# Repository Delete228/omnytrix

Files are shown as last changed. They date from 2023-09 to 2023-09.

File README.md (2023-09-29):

# omnytrix
Часы как у Бена Теннисона из одноименного мультфильма
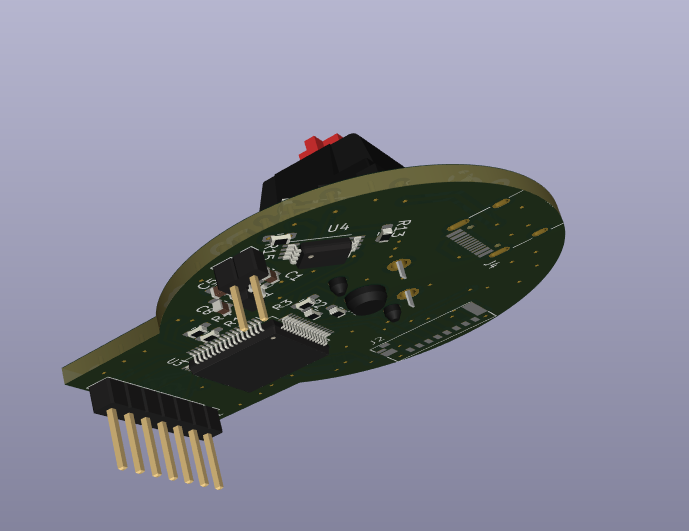
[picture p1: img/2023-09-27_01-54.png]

## Детали
### Корпус
Сам корпус нужно будет напечатать на 3D принтере и покрасить в нужные цвета.
### Дисплей
В основе лежит круглый дисплей 240x240 1.28, на контроллере GC9A01
### Мозги
Используеться микроконроллер stm32f411(выбран потому что в нем есть sdio)
### Управление
Нажание на часы реализованно с помощью свича от механической клавиатуры.
## Печать
Корпус еще в разработке
## TODO
* Добавить пины для программирования
* добавить разрыв в цепи 3.3v для измерения тока
* Добавить энкодер
* Подумать над кнопкой включения

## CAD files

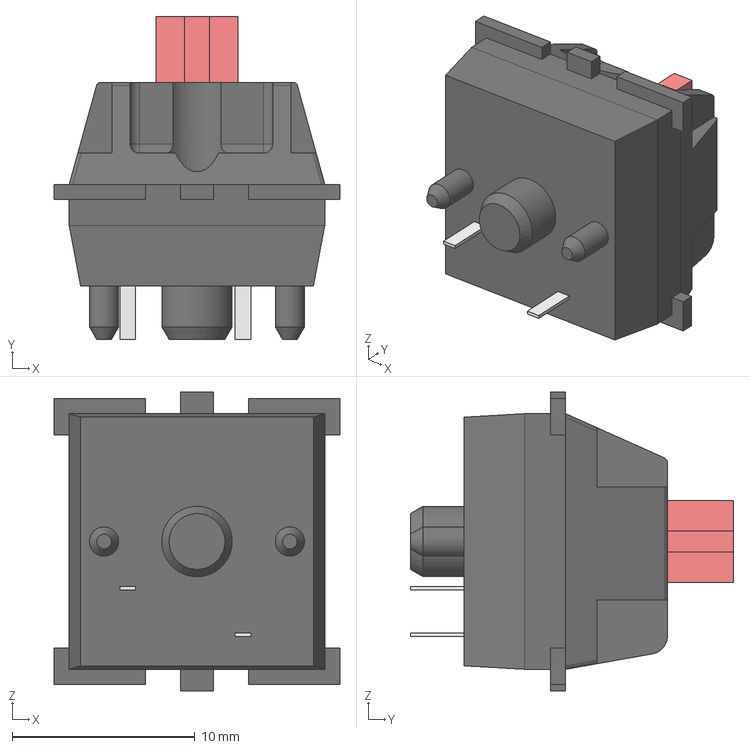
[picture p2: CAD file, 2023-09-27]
omnytrix_pcb/switch.step
15.6 x 17.7 x 16.3 mm

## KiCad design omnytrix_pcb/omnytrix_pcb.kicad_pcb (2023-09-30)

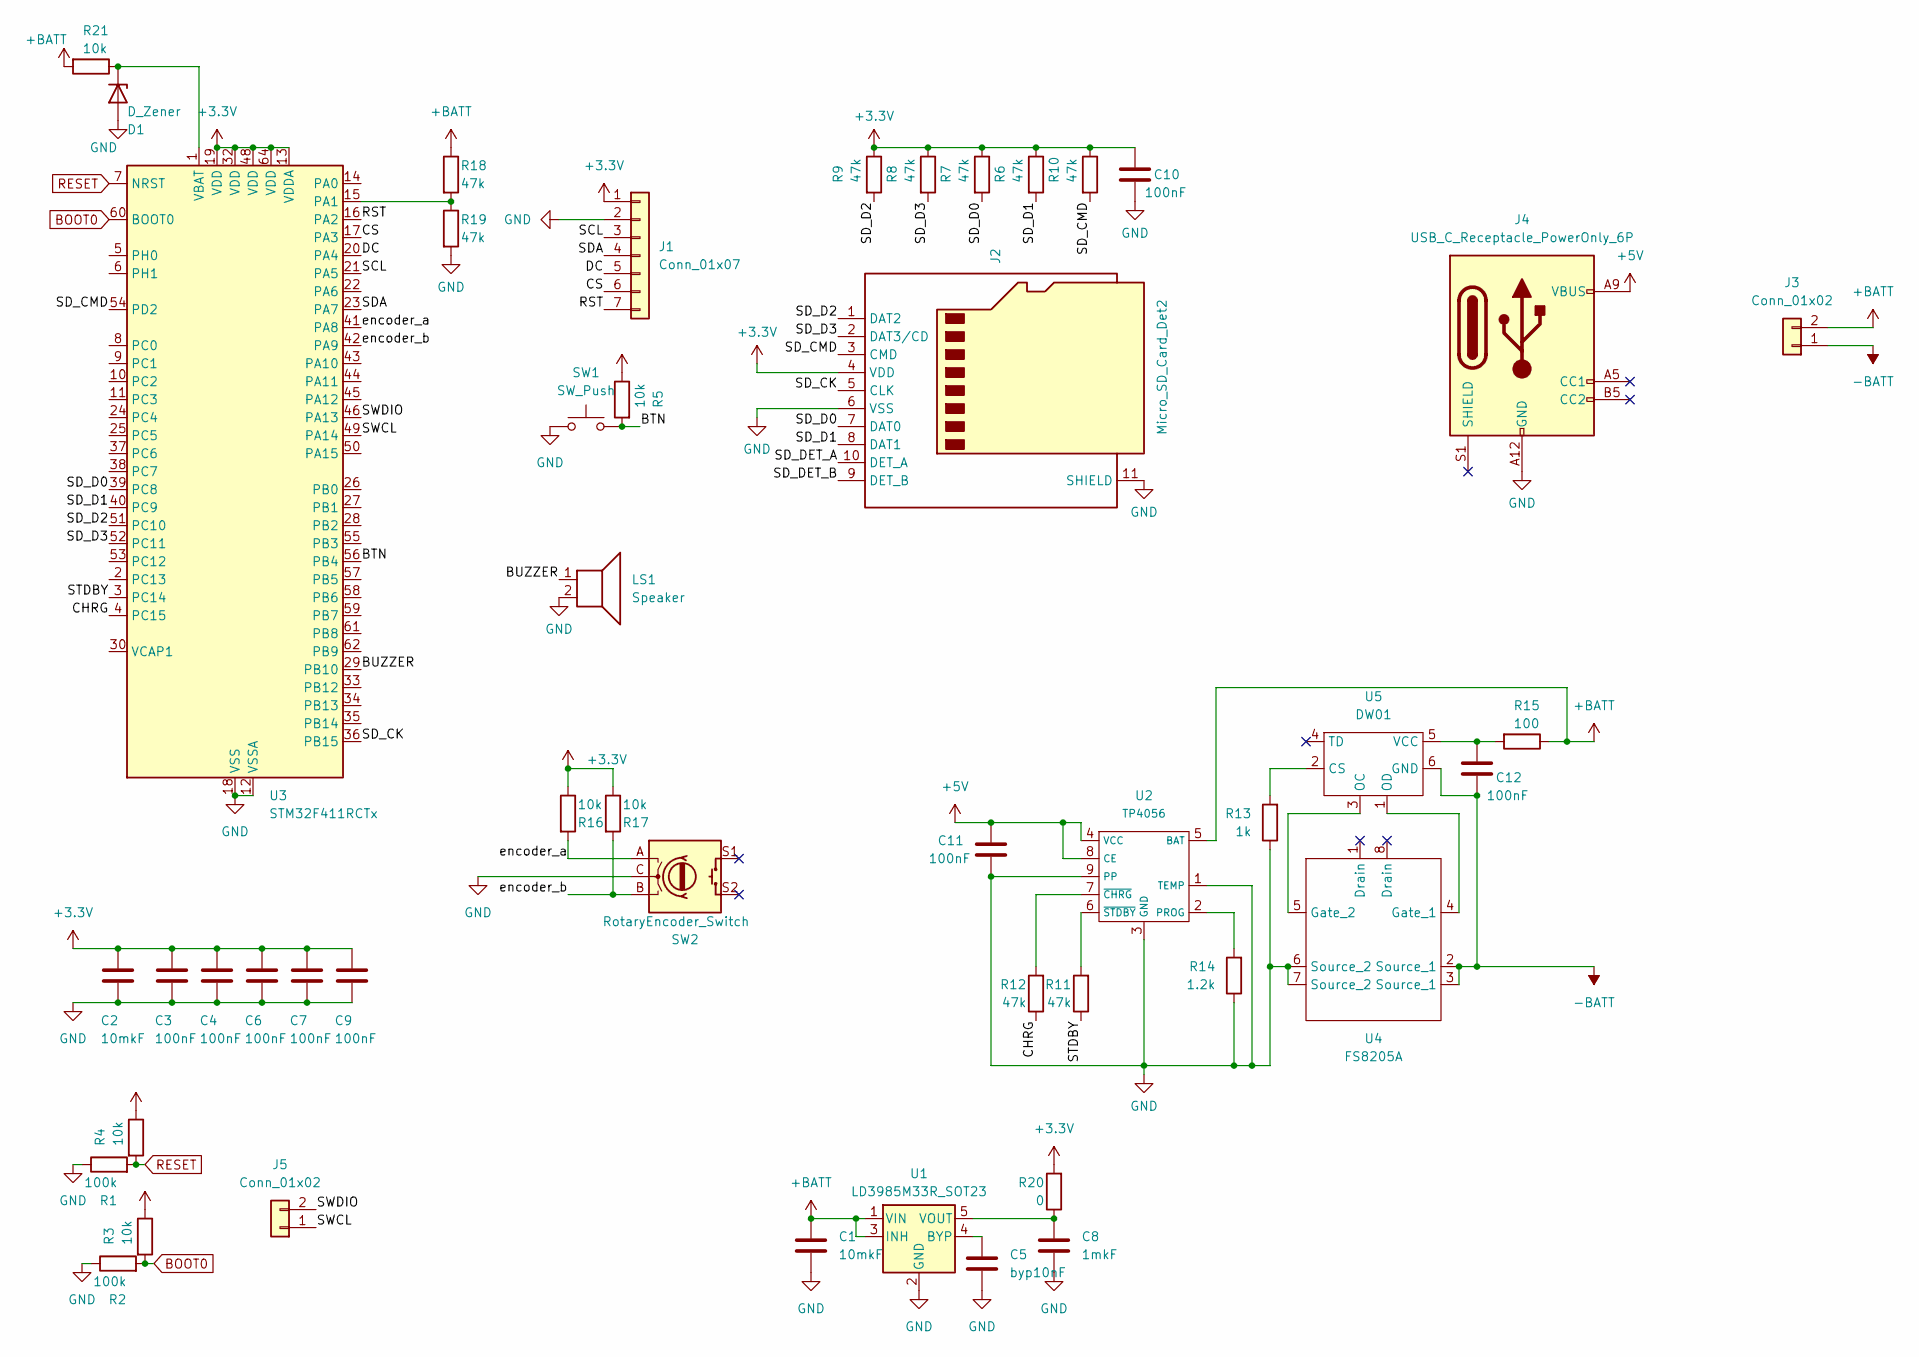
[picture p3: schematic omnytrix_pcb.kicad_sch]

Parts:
C1, C2: 10mkF; C_0603_1608Metric_Pad1.08x0.95mm_HandSolder
C3, C4, C6, C7, C9, C10, C11, C12: 100nF; C_0603_1608Metric_Pad1.08x0.95mm_HandSolder
C5: byp10nF; C_0603_1608Metric_Pad1.08x0.95mm_HandSolder
C8: 1mkF; C_0603_1608Metric_Pad1.08x0.95mm_HandSolder
D1: D_Zener; D_SOD-323_HandSoldering
J1: Conn_01x07; PinHeader_1x07_P2.54mm_Vertical
J2: Micro_SD_Card_Det2; microSD_molex
J3, J5: Conn_01x02; PinHeader_1x02_P2.00mm_Vertical
J4: USB_C_Receptacle_PowerOnly_6P; USB_C_Receptacle_HRO_TYPE-C-31-M-12
LS1: Speaker; smd_buzzer
R1, R2: 100k; R_0603_1608Metric_Pad0.98x0.95mm_HandSolder
R3, R4, R5, R16, R17, R21: 10k; R_0603_1608Metric_Pad0.98x0.95mm_HandSolder
R6, R7, R8, R9, R10, R11, R12, R18, R19: 47k; R_0603_1608Metric_Pad0.98x0.95mm_HandSolder
R13: 1k; R_0603_1608Metric_Pad0.98x0.95mm_HandSolder
R14: 1.2k; R_0603_1608Metric_Pad0.98x0.95mm_HandSolder
R15: 100; R_0603_1608Metric_Pad0.98x0.95mm_HandSolder
R20: 0; R_0603_1608Metric_Pad0.98x0.95mm_HandSolder
SW1: SW_Push; SW_Cherry_MX_1.00u_PCB
SW2: RotaryEncoder_Switch; EC11_encoder
U1: LD3985M33R_SOT23; SOT-23-5
U2: TP4056; SOIC-8-1EP_3.9x4.9mm_P1.27mm_EP2.29x3mm
U3: STM32F411RCTx; LQFP-64_10x10mm_P0.5mm
U4: FS8205A; TSSOP-8_4.4x3mm_P0.65mm
U5: DW01; SOT-23-6_Handsoldering

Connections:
+3.3V: C2.1, C3.1, C4.1, C6.1, C7.1, C9.1, C10.1, J1.1, J2.4 (VDD), R3.1, R4.1, R5.1, R6.1, R7.1, R8.1, R9.1, R10.1, R16.1, R17.1, R20.2, U3.13 (VDDA), U3.19 (VDD), U3.32 (VDD), U3.48 (VDD), U3.64 (VDD)
+5V: C11.1, J4.A9 (VBUS), J4.B9 (VBUS), U2.4 (VCC), U2.8 (CE)
+BATT: C1.1, J3.2, R15.1, R18.1, R21.2, U1.1 (VIN), U1.3 (INH), U2.5 (BAT)
-BATT: C12.2, J3.1, U4.2 (Source_1), U4.3 (Source_1), U5.6 (GND)
/BTN: R5.2, SW1.2, U3.56 (PB4)
/BUZZER: LS1.1, U3.29 (PB10)
/CHRG: R12.1, U3.4 (PC15)
/CS: J1.6, U3.17 (PA3)
/DC: J1.5, U3.20 (PA4)
/RST: J1.7, U3.16 (PA2)
/SCL: J1.3, U3.21 (PA5)
/SDA: J1.4, U3.23 (PA7)
/SD_CK: J2.5 (CLK), U3.36 (PB15)
/SD_CMD: J2.3 (CMD), R10.2, U3.54 (PD2)
/SD_D0: J2.7 (DAT0), R7.2, U3.39 (PC8)
/SD_D1: J2.8 (DAT1), R6.2, U3.40 (PC9)
/SD_D2: J2.1 (DAT2), R9.2, U3.51 (PC10)
/SD_D3: J2.2 (DAT3/CD), R8.2, U3.52 (PC11)
/SD_DET_A: J2.10 (DET_A)
/SD_DET_B: J2.9 (DET_B)
/STDBY: R11.1, U3.3 (PC14)
/SWCL: J5.1, U3.49 (PA14)
/SWDIO: J5.2, U3.46 (PA13)
/encoder_a: R16.2, SW2.A, U3.41 (PA8)
/encoder_b: R17.2, SW2.B, U3.42 (PA9)
BOOT0: R2.2, R3.2, U3.60 (BOOT0)
GND: C1.2, C2.2, C3.2, C4.2, C5.2, C6.2, C7.2, C8.2, C9.2, C10.2, C11.2, D1.2 (A), J1.2, J2.6 (VSS), J2.11 (SHIELD), J4.A12 (GND), J4.B12 (GND), LS1.2, R1.1, R2.1, R13.1, R14.1, R19.2, SW1.1, SW2.C, U1.2 (GND), U2.1 (TEMP), U2.3 (GND), U2.9 (PP), U3.12 (VSSA), U3.18 (VSS), U3.31 (VSS), U3.47 (VSS), U3.63 (VSS), U4.6 (Source_2), U4.7 (Source_2)
unnamed: D1.1 (K), R21.1, U3.1 (VBAT)
unnamed: C5.1, U1.4 (BYP)
unnamed: C8.1, R20.1, U1.5 (VOUT)
unnamed: R14.2, U2.2 (PROG)
unnamed: R12.2, U2.7 (~CHRG)
unnamed: R11.2, U2.6 (~STDBY)
unnamed: R18.2, R19.1, U3.15 (PA1)
unnamed: U4.4 (Gate_1), U5.1 (OD)
unnamed: U4.5 (Gate_2), U5.3 (OC)
unnamed: R13.2, U5.2 (CS)
unnamed: C12.1, R15.2, U5.5 (VCC)
RESET: R1.2, R4.2, U3.7 (NRST)

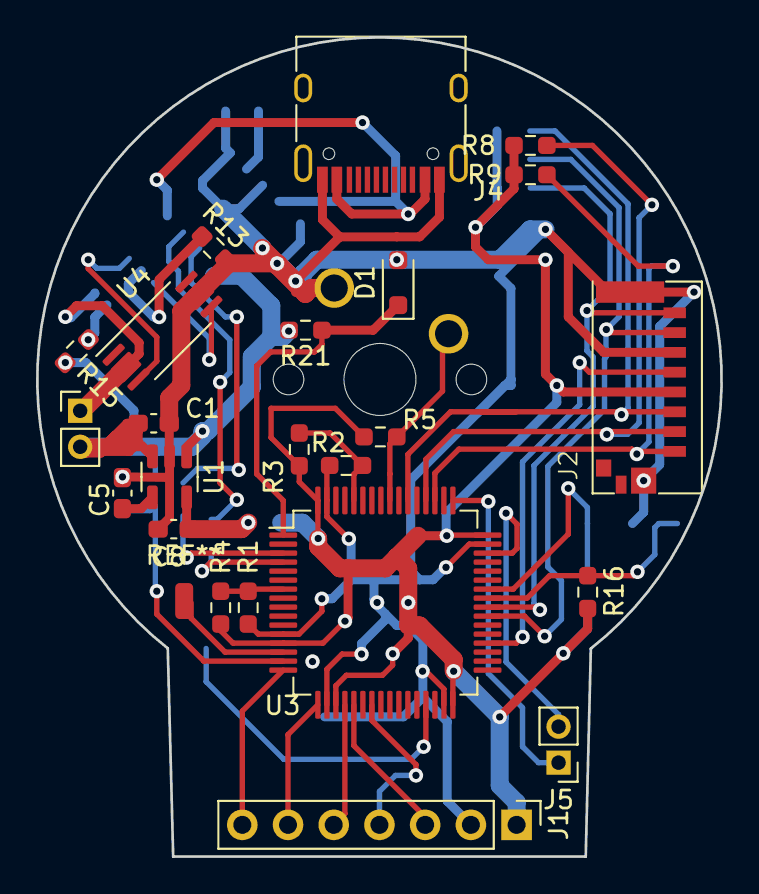
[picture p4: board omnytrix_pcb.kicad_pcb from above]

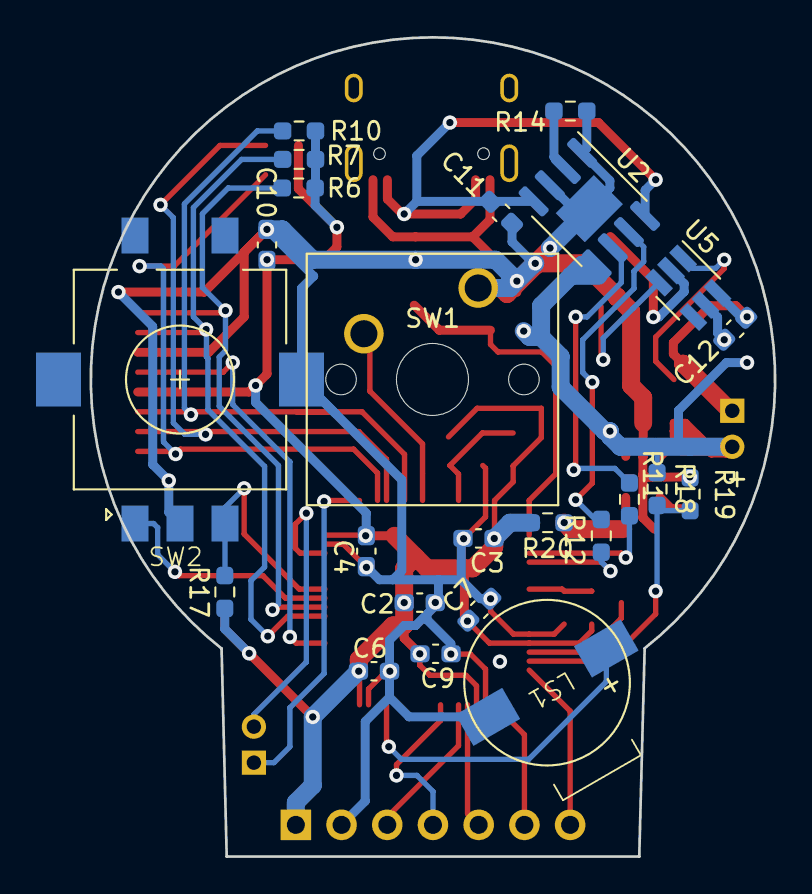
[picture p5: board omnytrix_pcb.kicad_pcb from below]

Board: 2 copper layers, 38.0 x 45.5 mm, 47 parts (24 on the bottom side), 37 nets.

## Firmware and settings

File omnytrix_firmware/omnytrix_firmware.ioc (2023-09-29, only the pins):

Mcu.UserName=STM32F411RCTx
PA1.Signal=ADCx_IN1
PA13.Signal=SYS_JTMS-SWDIO
PA14.Signal=SYS_JTCK-SWCLK
PA5.Signal=SPI1_SCK
PA8.Signal=S_TIM1_CH1
PA9.Signal=S_TIM1_CH2
PB10.Signal=S_TIM2_CH3
PB15.Signal=SDIO_CK
PB5.Signal=SPI1_MOSI
PC10.Signal=SDIO_D2
PC11.Signal=SDIO_D3
PC8.Signal=SDIO_D0
PC9.Signal=SDIO_D1
PD2.Signal=SDIO_CMD

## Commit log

2023-09-26 add pcb project
    [omnytrix_pcb.kicad_pcb, omnytrix_pcb.kicad_sch]
2023-09-26 trace stm32, power, display and switch
    [omnytrix_pcb.kicad_pcb, omnytrix_pcb.kicad_sch]
2023-09-26 add some R and change position of components
    [omnytrix_pcb.kicad_pcb, omnytrix_pcb.kicad_sch]
2023-09-27 add microsd
    [omnytrix_pcb.kicad_pcb, omnytrix_pcb.kicad_sch, switch.step]
2023-09-27 Test topor autotrace
    [omnytrix_pcb.dsn]
2023-09-27 compare topor and my trace
    [omnytrix_pcb.kicad_pcb]
2023-09-28 test topor trace
2023-09-28 add bat control
    Add battery controller TP4056
    [omnytrix_pcb.kicad_pcb, omnytrix_pcb.kicad_sch]
2023-09-28 add ground filled zone
    [omnytrix_pcb.kicad_pcb]
2023-09-29 add buzzer and encoder
    [omnytrix_pcb.kicad_pcb, omnytrix_pcb.kicad_sch]
2023-09-30 add vbat for rtc
    [omnytrix_pcb.kicad_pcb, omnytrix_pcb.kicad_sch]
